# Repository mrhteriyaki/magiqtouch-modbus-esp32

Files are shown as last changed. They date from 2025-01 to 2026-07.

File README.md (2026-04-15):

# MagIQTouch Modbus

This project is an alternative to the official WiFi Module for the MagiqTouch system.  
It provides local access and control with a simple [REST API](Docs/Api.md).

### Home Assistant Integration: 
[https://github.com/mrhteriyaki/magiqtouch-modbus-esp32-ha](https://github.com/mrhteriyaki/magiqtouch-modbus-esp32-ha)

### Tested Configuration and Limitations: [Link](Docs/Tested.md)

### Hardware List: [Link](Docs/HardwareList.md)

### API Documentation: [Link](Docs/Api.md)

### Configuration Steps:
1. Download and Install [Arduino IDE](https://www.arduino.cc/en/software/)
2. Download the contents of the folder [ArduinoControlLAN-AirconControl].
3. Open the file ArduinoControlLAN-AirconControl.ino the Arduino IDE should open.
4. Under Tools, Board manager install the package "esp32 by Espressif Systems" 
5. Select Tools > Port and select the port related to the ESP32 module.
6. Click the Upload button (Right pointing Arrow).
7. Once the upload is completed, restart the device to ensure it resets after the upload.
8. The device will then broadcast a local WiFi network named 'ESP32-AIRCON', connect to it with passkey 'ExtraTasty123!'
9. Browse to http://esp32-aircon.local/wifi (or http://192.168.4.1/wifi)  
10. Enter in your normal WiFi network name/password and click save.  
The device will then reboot and join the WiFi network with the provided details.  
(If you enter in the incorrect wifi details, you will need to re-flash with the 'erase all flash' option enabled to clear the saved settings.)
11. Confirm the device is accessible by browsing to http://esp32-aircon.local/  
A JSON formatted response is displayed similar to [this example](Docs/Api.md).  

Wiring diagram for the device:  
(Note Ethernet boards use alternate pins)  

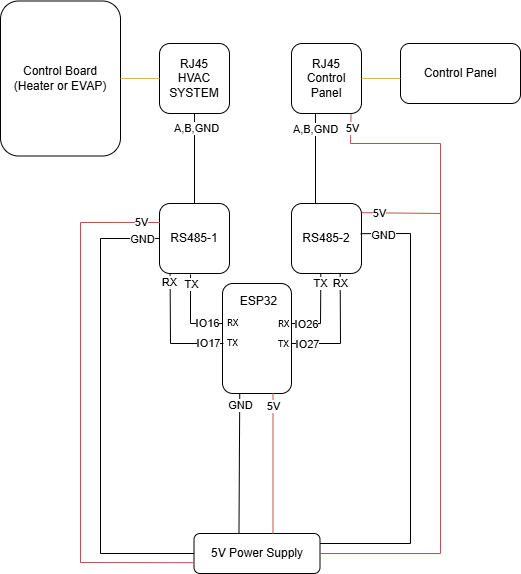
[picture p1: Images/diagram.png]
diagram


### For ethernet boards:
IO5  / RX2 -> RS485 Module 1 TX  
IO17 / TX2 -> RS485 Module 1 RX  
IO14 -> RS485 Module 2 TX  
IO15 -> RS485 Module 2 RX  

## RS485 to RJ45 Connector Wiring
The cables from the control panel and control board use a 6P6C male connector so that would be ideal.  
However I did not have one available in testing so for this will use a regular 8P8C Wall jack.

| RS485 Module | RJ45 Wire (A Wiring) |
|---|---|
| 5V (Control Panel Port Only) | Solid Green and Solid Orange |
| GND | Brown/White and Blue/White. |
| RS485 A | Solid Blue |
| RS485 B | Orange/White |

The standard 8P8C / RJ45 female ethernet wall jack can be used to connect to the cables to the device.  
The connector to the system board only requires A,B serial wires and ground.  
The connector to the control panel requires A,B, GND and 5V to power the panel.  

The 5v power should also be connected to the 5V Pin on the ESP32, to power both RS485 modules and one RJ45 ports for the control panel.  
The pinout on the rear of an RJ45 jack can vary with A/B positions, so make sure to match up the colours not positions in the image below. 

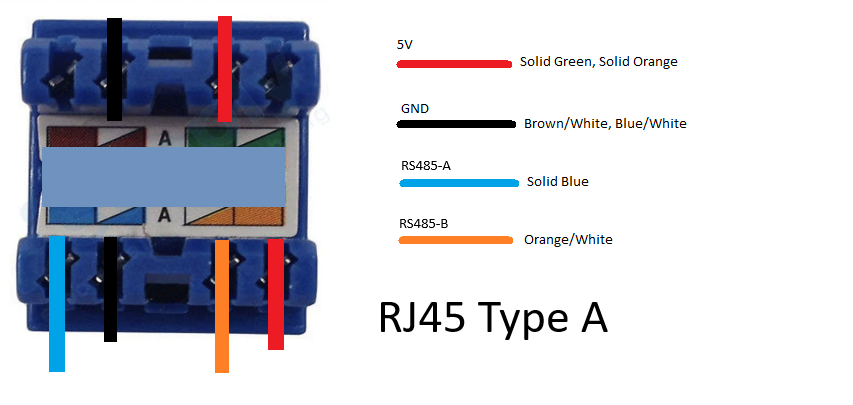
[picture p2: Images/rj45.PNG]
RJ45


Once you have wired up your device prepared, you should be able to connect it inbetween the heater unit control board and primary control panel.

If you are not replacing an existing WiFi module, you should be prompted when the module is detected to setup the WiFi settings, tap latter on this prompt.  
Try the the component configuration update if it does not show up in Settings -> Service.
[Instructions for detecting components](Docs/NewModule.md)

Here is my mess wired up inside a 3d printed housing, STL files for 3d printing available in the Housing-CAD-STL folder.  
(Image reflects older wiring with 9/10 pins, has been moved to use alternate pins since photo was taken.)  

insidebox

Mounted inside the return air wallspace:  
mounted

## More Technical Notes:

### Control Panel Wiring / Pin Information: [Link](Docs/ControllerWiring.md)

### MODBUS Information [Link](Docs/Modbus.md)

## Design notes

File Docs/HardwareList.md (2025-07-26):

[Back to Readme](../README.md)

Hardware List:
- ESP32 (Select One, these have been tested)
    - Wireless Options:
        - ESP32 WROOM-32 (Code runs on device, not tested connected to real system, should work)
        - FireBeetle ESP32 from [DFRobot](https://www.dfrobot.com/product-1590.html) - [Element14 Link](https://au.element14.com/dfrobot/dfr0478/firebeetle-esp32-iot-mcu-arduino/dp/3517881)
    - Wired Options:
        - WT32-ETH01 (Unit with Ethernet Port manufactured by Wireless Tag, requires a programmer [Link](https://core-electronics.com.au/usb-to-ttl-uart-rs232-serial-converter-module-pl2303hx-au-local-shipping.html))

- 2x RS485 Modules ([SeeedStudio Link](https://www.seeedstudio.com/Grove-RS485-p-2924.html) - 103020193)  Available in AUS at [Element14](https://au.element14.com/seeed-studio/103020193/serial-comm-board-rs485-arduino/dp/4007772) as "Serial Communication Board, RS485"
- 5V DC Power Supply

Cable / Connector List: 
- 2x RJ45 Connectors (Regular network jack, requires a 'punch down tool')
- Groove to Female Pin cables (SS110990028)
- 6P6C Cable if you are not replacing the original WiFi module.

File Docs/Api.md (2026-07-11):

[Back to Readme](../README.md)

## Web API Access and Control:

A GET Request to the module will return status info in JSON format.
Example of returned output.
```json
{
  "module_name": "ESP32-AIRCON",
  "uptime": "0d 00:05:11",
  "system_power": 0,
  "system_mode": 0,
  "target_temp": 20,
  "target_temp_zone2": 22,
  "evap_mode": 169,
  "evap_fanspeed": 0,
  "heater_mode": 0,
  "heater_fanspeed": 0,
  "heater_therm_temp": 16,
  "heater_zone1_enabled": 0,
  "heater_zone2_enabled": 0,
  "zone1_temp_sensor": 157,
  "zone2_temp_sensor": 20,
  "panel_command_count": 0,
  "automatic_clean_running": 0
}
```

Sending commands is simple using a POST request in plain/text to the path /command EG: http://192.168.20.112/command
The body should have a single command in the format setting=value

List of available commands, where x is the value.

| Command | Available Values | Function |
|---|---|---|
| power=x| on/off| System Power On or Off|
| zone1=x| on/off | Enable/Disable Zone 1 for Heater|
| zone2=x| on/off | Enable/Disable Zone 2 for Heater|
| fanspeed=x| 1-10 | Set Fan Speed for Fan, Cooler|
| mode=x| 0-4| Device Mode<br>0 = Fan Mode (External)<br>1 = Fan Mode (Recycle)<br>2 = Cooler (Manual)<br>3 = Cooler (Auto)<br>4 = Heater|
| temp=x| 0-28| Temperature Target for Cooler, Heater (Zone 1)
| temp2=x| 0-28| Temperature Target for Heater Zone 2|
| serial=x| on/off| Enables output of Modbus messages to Serial<br>Works with ModBusLogger tool on Serial message mode.|
| logging=x | 1.2.3.4 / off | Enable UDP stream of modbus messages for logging, supported with ModBusLogger tool.|

Additional endpoints are:
| URI Path | Function |
|---|---|
| /raw | Provides the raw output from the primary information modbus message sent from the panel to the IOT module. |
| /wifi | WiFi Configuration Setup Page |
| /network | Network information |
| /wifiupdate | Used by the wifi page to save WiFi settings to the device. |
| /clearsavedwifi | This will clear the saved WiFi settings and restore the default broadcasting AP. |

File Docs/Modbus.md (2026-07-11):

[Back to Readme](../README.md)

## MODBUS:
The [Modbus Codes.ods](../Modbus%20Codes.ods) file contains information about the modbus messages used on the network.
Messages are sent in pairs with a request and response message.
The document formats these by the Slave ID, Function Code, Request, Response with notes about the information found in these message pairs.

All devices are on the same single network, the primary / zone 1 control panel is the authorative device that sends the requests, all other devices respond.
Data that is requested from the control panel is typically sent with function 0x03 (read request) and information sent (write request) is with 0x10.

Known Slave IDs:
|Slave ID| Related Purpose|
|---|---|
|0x01 | Unknown|
|0x02 | Evap Unit|
|0x8C (140)| Unknown|
|0x8D (141)| Heater Unit|
|0x97 (151)| Control Panel 2|
|0xA5 (165)| Unknown|
|0xD4 (212)| Zone Controller by elimination � may also be shared heater|
|0xEB (235)| IOT WiFi Module|
|0xF4 (244)| Unknown|
|0xFA (250)| Unknown|
|0xFE (254)| Unknown|

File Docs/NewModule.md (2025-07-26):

[Back to Readme](../README.md)

## New Module Setup.
These are the steps to add the module to your system.
If you use the official WiFi IOT module these steps are not required as it should already be configured for your system.
Swapping from the official module to this ESP Module does not require reconfiguration.

1. Go to Settings -> General -> System Configuration (Bottom of the list)
If you are prompted for a code, try **7378** (this is the code printed in my manual, if it doesnt work check your manual as it has the service code).

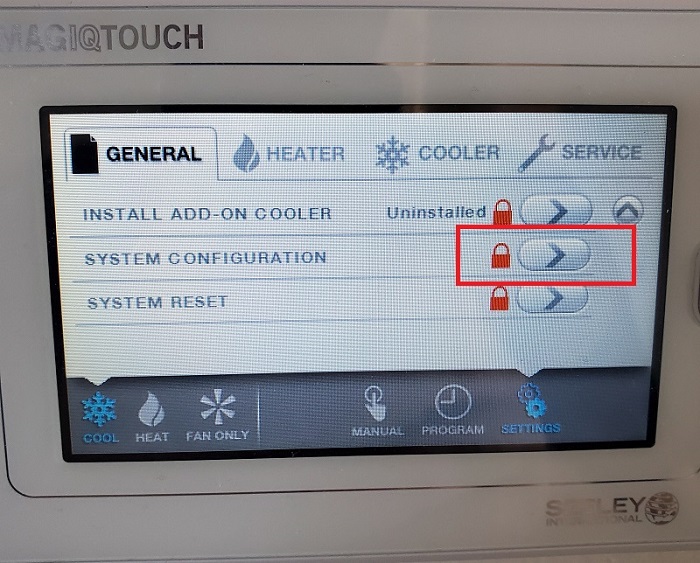
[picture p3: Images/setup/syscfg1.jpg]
syscfg1


2. Display or Modify existing System.
   
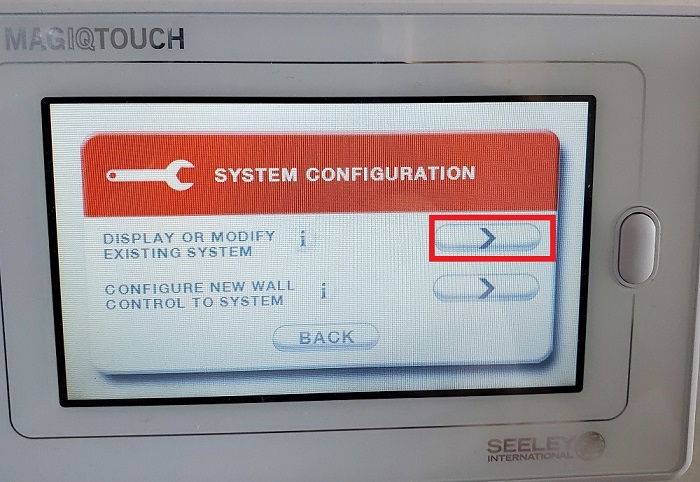
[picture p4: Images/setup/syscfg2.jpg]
syscfg2


3. Tap accept to start the system modbus scan.

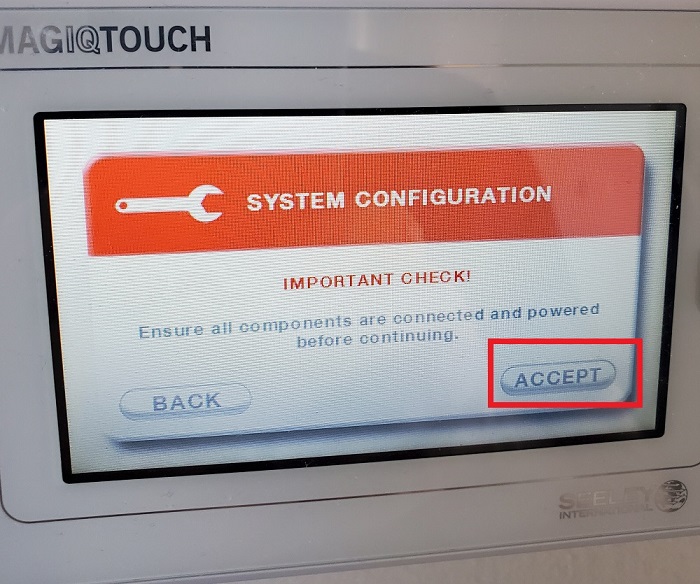
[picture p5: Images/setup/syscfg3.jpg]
syscfg3


4. It will scan for a couple minutes.

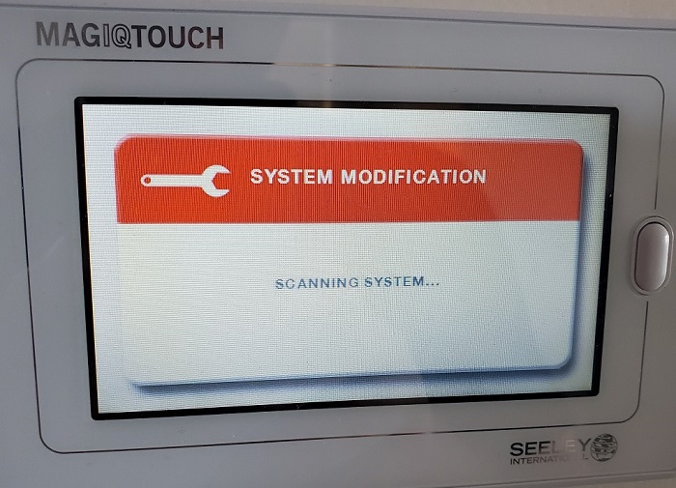
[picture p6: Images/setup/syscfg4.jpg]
syscfg4


5. When complete should display a summary of components on the system.

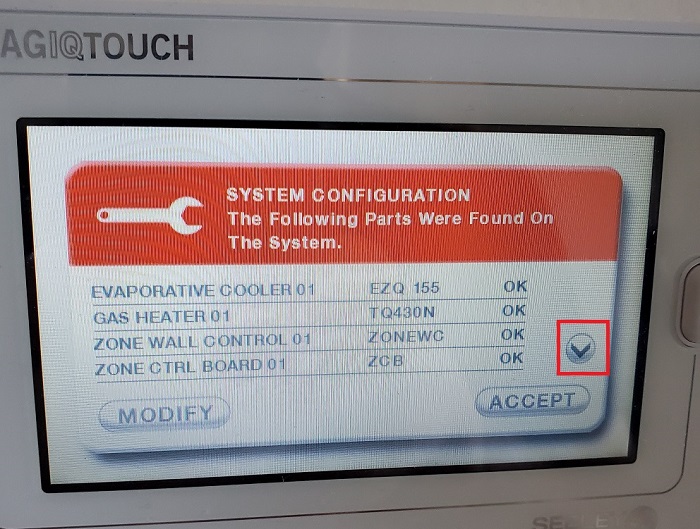
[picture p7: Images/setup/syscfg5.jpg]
syscfg5


6. The module should be detected as WiFi Smart Control, tap accept to complete the setup and the controller will restart.

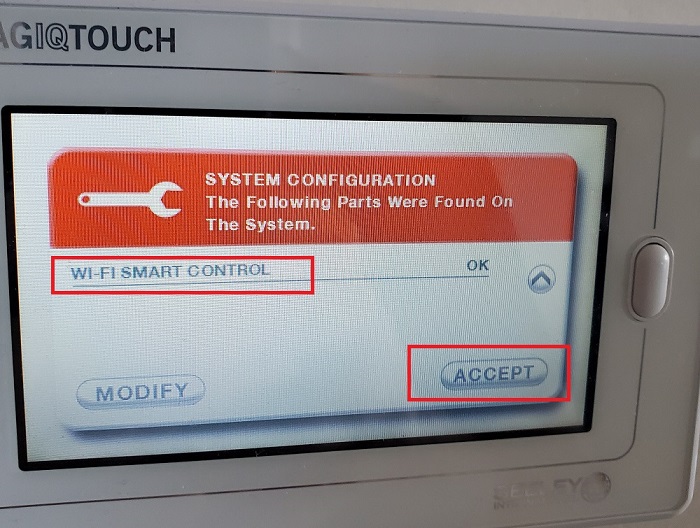
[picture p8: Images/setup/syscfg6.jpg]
syscfg6


7. Once the device startup is complete, it should be ready to go.
Note the WiFi status does not reflect the actual WiFi signal and uses a static code to fake the report.

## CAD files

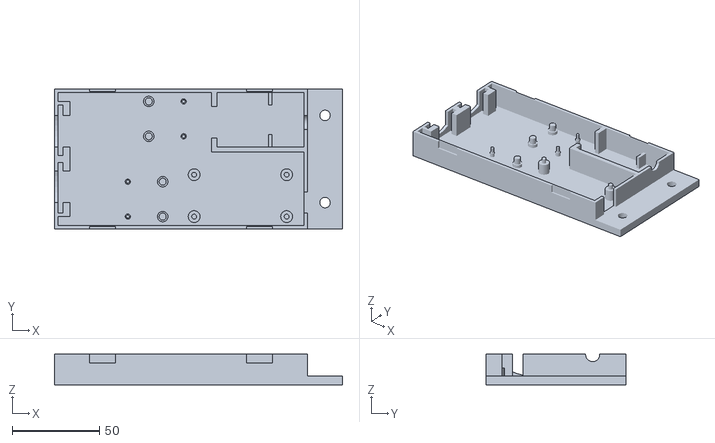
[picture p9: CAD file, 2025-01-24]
Housing-CAD-STL/Housing-Base.STL
165.0 x 80.0 x 17.5

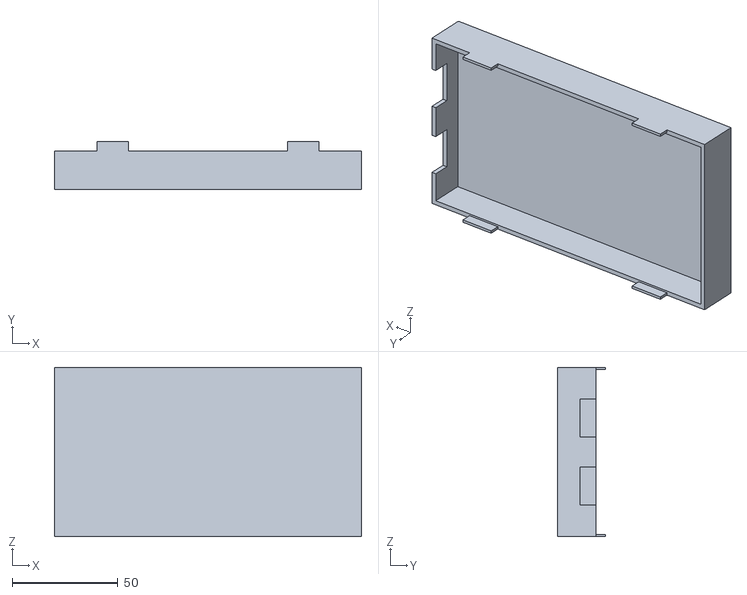
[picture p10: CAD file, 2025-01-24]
Housing-CAD-STL/Housing-CAP.STL
145.0 x 22.5 x 80.0

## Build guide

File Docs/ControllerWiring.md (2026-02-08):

[Back to Readme](../README.md)

Here's the pin layout for the original Connector too.  
Pinout

The GND and VCC are linked, purpose is likely to reduce cable resistance.  

| Pin | Wire Colour | Function |
|-----|---|---|
| 1 | Blue | VCC |
| 2 | Yellow | RS485-B  |
| 3 | Green | RS485-A  |
| 4 | Red | Ground |
| 5 | Black | VCC |
| 6 | White | Ground |

Tested VCC to Ground Voltage: 5.4V

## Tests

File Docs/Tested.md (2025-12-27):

[Back to Readme](../README.md)

## Tested and working with:  
- Evaporative Cooler (Breezair EZQ155)  
- Gas Heater (Braemar TQ430N)  
- 2 Zones  
- 2 Wall Controllers running software revision R719.  

## Known Limitations  
- Refrigerated Cooling not tested or supported.  
- Zones 3 & 4 not implemented. (Values are likely next in order from existing zone data)  
- Zone 1 temp sensor does not report correctly on non-temperature target modes  
  (Incorrectly reports temperature on app when using Fan modes or Cooler mode by fan speed).  
  Temp reporting issue occur with official module and app, not a limitation of this project.  
- Has only been tested with controller version R719.  
- WiFi controller status on control panel does not reflect actual ESP WiFi signal strength.  
- This project does not support the RF 'Wireless' Magiqtouch Controller as they do not support the official WiFi module.  
- On rare occasion module reports Fan / Cooler mode incorrectly as change is not sent by Controller messages.  
 (Example: Mode is swapped from Fan to Cooler on control panel, WiFi module will still think mode is on external fan)

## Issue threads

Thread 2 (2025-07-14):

Why two serial interfaces?

rlights, 2025-07-14:
I'm planning to build an interface in the near future and was very pleased to come across someone else having already done the hard work! So thankyou @mrhteriyaki for your efforts so far. The magiqtouch seems rather ubiquitous around Melbourne so this is helpful for a _lot_ of people.

However I'm very curious - why the two separate serial interfaces? The modbus interface shared between Seeley/ Braemar HVAC appliances (at least those compatible with the magiqtouch panels) is, well, a bus. Everything links together in parallel. As far as I can tell, the wifi module just offers two ports for physical convenience - so you don't need to purchase a link module as well, for most installations. I can't find anywhere a specification that one port or the other must face towards the appliance or the control panel. All together, I'm all but certain the two jacks are wired parallel.

Admittedly I can't find any information or images detailing the inside of the wifi module, but from looking at your code, the two interfaces are effectively back to back coupled via software anyway, with a background thread mirroring one to another & your write function writing to both simultaneously. Considering this I'm not entirely clear on what could be gained by gapping them like this instead of just using a single rs485 hardware interface and wiring the two jacks in parallel. Using a single interface would significantly reduce the complexity of both the hardware and software.

Have you had your original factory iot interface module apart? Care to share any images?

mrhteriyaki, 2025-07-14:
It's to determine the direction of the messages and which slave ID belongs to what.
I started with the monitor version and ran it as a simple proxy so it wouldn't cause any issues while the system ran normally.

So yeah it's probablly not needed outside of the development stage.

There's a fair few improvements that could be made but the interest has been low for actually building the project.
I think the barrier of actually assembling components is a non starter for many even in the home auto community.

I do have photos of the official board.
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

rlights, 2025-07-15:
Ah excellent, thanks for the confirmation. That looks like a rather well engineered board, it's rare to see consumer facing products that haven't been at least somewhat value optimised. But from what I've seen that's typical of Seeley - great hardware and lackluster software.
I would tend to agree that diy hardware can be a pretty big hurdle for a lot of HA folk. Might do something about that.

I gather from your various posts & comments that you have a limited number of system components to test the protocol against. I imagine most people will be in a similar situation with a slightly different selection, so it's well worth maintaining some monitor functionality. Perhaps it could even be the default first-boot mode so the datagrams can be sanity checked against what's on the wire before accidentally sending something inappropriate.
This would obviously also help a lot with extending the protocol definition for hardware we don't have.

There is one thing that might be reason enough to at least retain the possibility of two isolated serial ports:
I did originally consider using this interface module to feed in a temperature value from HA, instead of what is reported by the panel, but if only using a single serial interface that might be a lot harder. I think there are valid system configurations where the temperature probe in the panel is not used for zone temperature, but I'm really not clear on that, have you seen any data that confirms either way whether a different sensor can be configured to be the authoritative zone temperature?

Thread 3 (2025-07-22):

Compilation error on recent update

atomic10, 2025-07-22:
First off, thanks for this project. Home assistant control of my gas heater is exactly what I am looking for so I appreciate the time you have spent on building this.

With the update to V3 Espressif board library, I get a compile error with the following message
"Compilation error: 'DisconnectCheck' is not a member of 'LanController'"

I have updated all libraries that are in this project and I am using Arduino 2.3.6 IDE.
Also, Ihave tried with Espressif board library 3.0 & 3.2.1

If I comment the line out

```
void WebServerTask(void* parameter) {
  server.on("/", HTTP_GET, webRootResponse);
  server.on("/command", HTTP_POST, webCommandResponse);
  server.begin();

  while (true) {
    server.handleClient();
//    LanController::DisconnectCheck();
    vTaskDelay(1);
  }
}
```

It compiles, but Home assistant shows it as unavailable (was showing correct temp & correct set temp on previous version), and now when I go to the ESP32 IP address, it shows the JSON data, but appears to be adding data like a log file.
Below is a snippet

`{
  "module_name": "ESP32-HVAC-Control",
  "uptime": "00:00:11",
  "system_power": 0,
  "system_mode": 0,
  "target_temp": 0,
  "target_temp_zone2": 0,
  "evap_mode": 0,
  "evap_fanspeed": 0,
  "heater_mode": 0,
  "heater_fanspeed": 0,
  "heater_therm_temp": 0,
  "heater_zone1_enabled": 0,
  "heater_zone2_enabled": 0,
  "zone1_temp_sensor": 0,
  "zone2_temp_sensor": 0,
  "panel_command_count": 0,
  "automatic_clean_running": 0,
  "eb1008e60032_cp1data": "0,0,0,0,0,0,0,0,0,0,0,0,0,0,0,0,0,0,0,0,0,0,0,0,0,0,0,0,0,0,0,0,0,0,0,0,0,0,0,0,0,0,0,0,0,0,0,0,0,0,0,0,0,0,0,0,0,0,0,0,0,0,0,0,0,0,0,0,0,0,0,0,0,0,0,0,0,0,0,0,0,0,0,0,0,0,0,0,0,0,0,0,0,0,0,0,0,0,0,0,0,0,0,0,0,0,0,0,0"
}{
  "module_name": "ESP32-HVAC-Control",
  "uptime": "00:00:12",
  "system_power": 0,
  "system_mode": 0,
  "target_temp": 0,
  "target_temp_zone2": 0,
  "evap_mode": 0,
  "evap_fanspeed": 0,
  "heater_mode": 0,
  "heater_fanspeed": 0,
  "heater_therm_temp": 0,
  "heater_zone1_enabled": 0,
  "heater_zone2_enabled": 0,
  "zone1_temp_sensor": 0,
  "zone2_temp_sensor": 0,
  "panel_command_count": 0,
  "automatic_clean_running": 0,
  "eb1008e60032_cp1data": "0,0,0,0,0,0,0,0,0,0,0,0,0,0,0,0,0,0,0,0,0,0,0,0,0,0,0,0,0,0,0,0,0,0,0,0,0,0,0,0,0,0,0,0,0,0,0,0,0,0,0,0,0,0,0,0,0,0,0,0,0,0,0,0,0,0,0,0,0,0,0,0,0,0,0,0,0,0,0,0,0,0,0,0,0,0,0,0,0,0,0,0,0,0,0,0,0,0,0,0,0,0,0,0,0,0,0,0,0"
}{
  "module_name": "ESP32-HVAC-Control",
  "uptime": "00:00:13",
  "system_power": 0,
  "system_mode": 0,
  "target_temp": 0,
  "target_temp_zone2": 0,
  "evap_mode": 0,
  "evap_fanspeed": 0,
  "heater_mode": 0,
  "heater_fanspeed": 0,
  "heater_therm_temp": 0,
  "heater_zone1_enabled": 0,
  "heater_zone2_enabled": 0,
  "zone1_temp_sensor": 0,
  "zone2_temp_sensor": 0,
  "panel_command_count": 0,
  "automatic_clean_running": 0,
  "eb1008e60032_cp1data": "0,0,0,0,0,0,0,0,0,0,0,0,0,0,0,0,0,0,0,0,0,0,0,0,0,0,0,0,0,0,0,0,0,0,0,0,0,0,0,0,0,0,0,0,0,0,0,0,0,0,0,0,0,0,0,0,0,0,0,0,0,0,0,0,0,0,0,0,0,0,0,0,0,0,0,0,0,0,0,0,0,0,0,0,0,0,0,0,0,0,0,0,0,0,0,0,0,0,0,0,0,0,0,0,0,0,0,0,0"
}{
  "module_name": "ESP32-HVAC-Control",
  "uptime": "00:00:14",
  "system_power": 0,
  "system_mode": 0,
  "target_temp": 0,
  "target_temp_zone2": 0,
  "evap_mode": 0,
  "evap_fanspeed": 0,
  "heater_mode": 0,
  "heater_fanspeed": 0,
  "heater_therm_temp": 0,
  "heater_zone1_enabled": 0,
  "heater_zone2_enabled": 0,
  "zone1_temp_sensor": 0,
  "zone2_temp_sensor": 0,
  "panel_command_count": 0,
  "automatic_clean_running": 0,
  "eb1008e60032_cp1data": "0,0,0,0,0,0,0,0,0,0,0,0,0,0,0,0,0,0,0,0,0,0,0,0,0,0,0,0,0,0,0,0,0,0,0,0,0,0,0,0,0,0,0,0,0,0,0,0,0,0,0,0,0,0,0,0,0,0,0,0,0,0,0,0,0,0,0,0,0,0,0,0,0,0,0,0,0,0,0,0,0,0,0,0,0,0,0,0,0,0,0,0,0,0,0,0,0,0,0,0,0,0,0,0,0,0,0,0,0"
}`

Let me know if you need more info.

atomic10, 2025-07-23:
Thanks for the info. Will have a play over the weekend. The 1 degree increment is working as intended and temp sensor isn't working even with primary zone on, although I'm not convinced that I have everything perfect with my setup.

The heater I have is the TQS730. Single zone with no cooling.

It would be strange for them to change the Modbus structure of registers and coils between models but not impossible I guess. Tempted to get an IOT module just to be able to reverse engineer the messages and compare your findings.

Closed 2025-07-23.

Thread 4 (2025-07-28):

Connecting module makes all HVAC components "not detected"

unahmean, 2025-07-28:
Hi and thanks for your work on this project. I have wanted to integrate the MagiQtouch with HA for some time but was not a fan of the official wifi module so I was excited to try this.

I built this device a couple of months ago, but was not able to get it to work.

I have tried using both the Firebeetle ESP32 and a WT32-ETH01.
I have tried several different types of RS-485 modules that I had on hand (not the seed studio ones though) but they are otherwise identical on paper.
Flashed the ESP32 boards fine, they connect to the network and the webpage displays fine.
Wired everything up according to the diagram.
MagiQtouch software revision is R719.

The issue I am having is when I connect it inline with MagiQtouch controller and the heater control board, once it boots up, the controller reports that all of the components are not detected. The heater, evap cooler and an air sensor are all not detected. Scanning does nothing to fix the problem. Appears to not be chatting over modbus but I can't work out why.

Do I need to use the seed studio RS-485 modules? I have flashed and rewired/checked this thing so many times and spent days trying to troubleshoot.

I put it away out of frustration but pulled it out again over the weekend once I saw there was some work getting it to use Espressif version 3.x, but that did not help either.

Any ideas or help would be greatly appreciated.

mrhteriyaki, 2025-07-28:
That does sound like an issue with the RS485 modules and it's not relaying the messages if you're getting those errors.

Do the RS485 modules your using have a 120 ohm termination resistor built in?
The groove modules I'm using do, but I recall testing some other generic ones previously that did not so possibly that's the issue?

unahmean, 2025-07-29:
Hey thanks for that and I thought you were on to something here - the RS485 modules are meant to include the 120 ohm resistor, but I measured between A and B and they were not.

I checked out the schematic and to enable it you have to short out some solder pads. So I did this, and confirmed with a multimeter that it was now reading 120 ohms between A and B, but unfortunately the same issue still exists. Components not detected/not found with the device inline.

I also tried adding some actual metal film 120 ohm resistors to another pair of RS485 modules but no luck there either.

I will play some more but may have to get the grove rs485 modules to rule that out. Strange though as there really is not much to them.

mrhteriyaki, 2025-07-29:
The MAX485 has DE/RE in addition to RX/TX, but doesn't look like any have those so not the issue.

The HW-519 looks like it has LED indicators, do you see any flashes when the control panel is connected to it?
Even when it has that no components found error it's constantly sending messages so should see an indicator light up for RS485 RX.

Also have you tried swapping the A/B connections?

unahmean, 2025-08-01:
Thanks for your continued help! I saw the update to the documentation regarding A/B.

I can also confirm that on those modules the labelling is backwards - TX is acting as an input and RX as an output.

So I hooked it up correctly for my scenario, the MagiQtouch controller boots up and the heater, evap and air sensor are all found okay as per normal.

The issue I described two posts above remains.

1. Enter system configuration, scan for new components - only heater, evap and air sensor are detected.
2. Click Accept, reboots and returns to the default main screen.
3. Disconnect the RX and TX pins on the RS485 module leading to the heater's control board.
4. WiFi then appears on the main screen in green text. (note: this is without scanning for new components)
5. Other components heater, evap, air sensor drop off as not detected (obviously).
6. Reconnect RX and TX pins on the RS485 module leading to the heater's control board.
7. Green WiFi text disappears and an error message pops up "Wi-Fi Smart Control was not detected"
8. All other HVAC components are restored and functional.

I have tested with multiple RS485 modules, two ESP32 boards, with and without 120 ohm termination resistors.

I don't really want to factory reset the MagiQtouch controller but I have not tried that yet.

Any thoughts?

The air sensor is an "external air sensor" attached to the evap cooler on the roof. It doesn't appear that your setup has that, which is all I can think of hardware wise. I could climb up on the roof and disconnect it to test perhaps.

mrhteriyaki, 2025-08-01:
Glad to help, unfortunate it's hit another road bump.
RS485 issues seem resolved, If the devices are seen then it's proxying the messages.

My guess is there's some unexpected state the control panel is getting into when everything is connected and it's ignoring the IOT module.

I tested a reset myself and re-connected my esp32 module after the setup and it added itself after a half minute or so, the device update does not seem to be needed.

The air sensor does sound like a good next step to try, It would make sense that an external air sensor would change something in the IOT request/response packets that it's not accounting for.

Other options are to enable the serial output using a web request with serial=on
Then log all the modbus output from that and I can try to compare them to the existing known messages to see what's different.

mrhteriyaki, 2025-08-04:
Can you run the system configuration -> modify scan and send the serial output?

Looking at just the heater boot up process, it sends discovery messages for each of the slave IDs but skips over the ones for the IOT module (EB) so it doesn't seem to consider it part of the system.

I've got a few more tests I can run on my end but all going to take a while.
I'm a little bit suss on the RS485 modules being a problem, which ones did you end up using from the 3 you listed?

The basic relay process reads and then writes the byte to the other serial, but the processing can have timing issues if the RS485 boards are different to the Groove ones.
I have a feeling it may be failing to decode the messages and dropping them which wouldn't show up in the serial output, so the control panel may well be sending the messages for it to respond to.
The increased volume of messages with other modules also connected would explain why it drops off when the other devices are connected.

The software version on my heater unit is also listed as V1.09 and the messages all appear to be the same so I have a feeling the software is probably the same despite different model heater.

unahmean, 2025-08-05:
Thanks for looking into it and no worries if it is going to take some time to test on your end.

Here is the serial output for the system config -> modify, the scan process starts at line 32

[magiqtouch_scan_for_components.log](https://github.com/user-attachments/files/21595613/magiqtouch_scan_for_components.log)

As for the RS485 modules, I have tried multiple pairs of HW-519's and a pair of HW-726 - same behavior on all.

I may try and order some of the grove modules to eliminate that possibility, but these ones seem to work well otherwise.

Good to know that the heater PCB is likely the same.

mrhteriyaki, 2025-09-07:
Parts arrived a week or two ago, will let you know when I've tested them.

mrhteriyaki, 2025-09-13:
So tested it and HW-519 does work, with and without termination resistor interestingly.
There is a difference I found, the 3rd terminal on the RS side is not bridged to Ground.
Compared to the Groove module the ground on the RS side and UART side both have a 0 ohm resistance on the multimeter.
Have you bridged the RS reference terminal with GND using a separate wire?
How are your GND wires/points wired up?

mrhteriyaki, 2025-09-20:
On the HW-519 board to the control panel I bridged both grounds on the board itself with another wire.
The Grove modules have these internally bridged, the hw-519 seems to have some lightning protection component which I'm guessing splits it. As the control panel uses that same ground for power ground not just signal I would expect it cannot be isolated.

I went to use mine today (first time since putting these in) and it threw a comm error for the other system components.
Connecting the control panel directly works fine so not a system issue.
Swapped back to the Grove modules and it's working again.
There seems to be a few differences that don't make these boards a drop in replacement for the grove one.

unahmean, 2025-10-04:
So I had some Grove modules on order, they arrived, and I finally got around to trying them out in the past couple of days. As you have suggested - they worked fine. Everything is working properly now! Sorry for wasting your time with all of this but I guess something was learned through all of it.

Thanks again for your excellent work on this project and for your help, glad to finally have it fully functioning.

One extra thing I can let you know is that I am running my setup entirely on the heater control board's bus power. The ESP32 board, the modules and the magiqtouch screen all being powered with no issue. So no external power supply required for me which is great.

Feel free to close this issue now, unless you want any more info about anything.

Cheers!

mrhteriyaki, 2025-10-05:
Glad to hear it's working, am still a little surprised they worked.
Eventually I'll put the modules under the oscilloscope and see what it's doing at the wire level, guessing some sort of timing difference.

Closed 2025-10-05.

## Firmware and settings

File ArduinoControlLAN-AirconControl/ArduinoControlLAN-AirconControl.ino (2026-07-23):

// ESP32 Aircon Interface
// Board Library esp32 by Espressif Systems in use.

// Libraries.
#include <WebServer.h>
#include <ArduinoJson.h>
#include <esp_timer.h>
#include <HardwareSerial.h>
#include <WiFi.h>
#include <WiFiUdp.h>


#include "NetworkSettings.h"
#include "PinSettings.h"

// Max message size for modbus, reduce due to ram usage.
#define MAXMSGSIZE 256
#define MAXSLAVEID 30
#define GAPTHRESHOLD 50

WebServer server(80);


HardwareSerial SerialA(1);
HardwareSerial SerialB(2);

SemaphoreHandle_t msgSemaphore;

unsigned long s1previousMillis = 0;
uint8_t SerialAbuffer[MAXMSGSIZE];
int SerialAIndex = 0;

unsigned long s2previousMillis = 0;
uint8_t SerialBbuffer[MAXMSGSIZE];
int SerialBIndex = 0;

bool SerialOutputModbus = false;

bool MonitorMode = false;

// UDP Logging - mirrors SerialPrintMessage output to a remote host.
// Messages are queued here and sent from UdpLogTask so the modbus relay loop is never blocked by the network stack.
#define UDPLOGPORT 20000
#define UDPLOGQUEUELEN 8

struct UdpLogEntry {
  uint8_t data[MAXMSGSIZE + 2];  // +2 allows for CRC appended by SendMessage.
  int length;
  int serialID;
};

bool UdpLoggingEnabled = false;
IPAddress UdpLogHost;
WiFiUDP UdpLogger;
QueueHandle_t udpLogQueue;

// Aircon Control Variables.
bool SystemPower = false;
uint8_t FanSpeed = 1;
uint8_t SystemMode = 0;
uint8_t TargetTemp = 20;
uint8_t TargetTemp2 = 20;
bool HeaterZone1 = false;
bool HeaterZone2 = false;

// Aircon Info Variables.
uint16_t CommandInfo = 0x0;  // Increments on command change from Control Panel.
uint8_t SystemPowerInfo = 0x0;
uint8_t EvapModeInfo = 0x0;
uint8_t EvapFanSpeedInfo = 0x0;

uint8_t HeaterModeInfo = 0x0;
uint8_t HeaterFanSpeedInfo = 0x0;
uint8_t Zone1EnabledInfo = 0x0;
uint8_t Zone2EnabledInfo = 0x0;
uint8_t Zone1TempInfo = 0x0;
uint8_t Zone2TempInfo = 0x0;
uint8_t TargetTempInfo = 0x0;
uint8_t TargetTemp2Info = 0x0;
uint8_t ThermisterTempInfo = 0x0;
uint8_t AutomaticCleanRunning = 0x0;

// Derived from panel info. Reporting only.
bool initialSyncDone = false;  // No valid panel state known until first resync.
bool resyncPending = true;
uint8_t ReportedMode = 0x0;
uint8_t ReportedFanSpeed = 0x0;

bool sendCommand = false;
uint8_t IOTModuleCommandRequest[] = { 0xEB, 0x03, 0x0B, 0x0C, 0x00, 0x0D, 0x50, 0xE2 };
uint8_t x2vl = 0x9F;  // Increases for each command sent.
uint8_t x3vl = 0x21;  // WiFi DB Signal
uint8_t x4vl = 0x11;  // System Off 10 = On, 11 = Off.
uint8_t x5vl = 0x42;  // Cooler Mode 42 = Off, 02 = On
uint8_t x6vl = 0x43;  // Evap Fan setting.
uint8_t x7vl = 0x04;  // Unknown
uint8_t x8vl = 0x22;  // Heater Fan Settings.

uint8_t x10v = 0x24;
uint8_t x12v = 0x24;
uint8_t x14v = 0x00;  // zone control.

uint8_t x17v = 0x14;  // Zone 2 Temp - Default 20C
uint8_t x18v = 0x14;  // Zone 1 Temp

// Request for IOT Module info - Sends MAC address.
uint8_t IOTModuleInfoRequest[] = { 0xEB, 0x03, 0x03, 0xE4, 0x00, 0x05, 0xD3, 0x70 };
uint8_t IOTModuleInfoResponse[] = { 0xEB, 0x03, 0x0A, 0x01, 0x09, 0x01, 0x09, 0x70, 0x90, 0x2C, 0x65, 0x27, 0x0B };  // 13 bytes length, does not include CRC (0xA8, 0x11)

// 0xEB, 0x03, 0x0A, Version, MAC ADDRESS, 0xA8, 0x11
// Version is 0x01, 0x09, 0x01, 0x09
// MAC Address = 90:70:65:2C:0B:27

// Recurring responses that match the start of the request sent from CP1 - Function 10 Response.
uint8_t eb1005d80023[] = { 0xEB, 0x10, 0x05, 0xD8, 0x00, 0x23, 0x17, 0xED };  // CRC included.
uint8_t eb1005fb0021[] = { 0xEB, 0x10, 0x05, 0xFB, 0x00, 0x21, 0x67, 0xE6 };
uint8_t eb10061c002c[] = { 0xEB, 0x10, 0x06, 0x1C, 0x00, 0x2C, 0x16, 0x50 };
uint8_t eb1006480004[] = { 0xEB, 0x10, 0x06, 0x48, 0x00, 0x04, 0x57, 0x9E };
uint8_t eb10064C0038[] = { 0xEB, 0x10, 0x06, 0x4C, 0x00, 0x38, 0x16, 0x4E };
uint8_t eb100684002a[] = { 0xEB, 0x10, 0x06, 0x84, 0x00, 0x2A, 0x17, 0xBD };
uint8_t eb1006ae002a[] = { 0xEB, 0x10, 0x06, 0xAE, 0x00, 0x2A, 0x36, 0x75 };
uint8_t eb1006d80019[] = { 0xEB, 0x10, 0x06, 0xD8, 0x00, 0x19, 0x97, 0xBA };
uint8_t eb1008e50001[] = { 0xEB, 0x10, 0x08, 0xE5, 0x00, 0x01, 0x04, 0x94 };  // Info from CP1 to IOT for On/Off State.
uint8_t eb1008e60032[] = { 0xEB, 0x10, 0x08, 0xE6, 0x00, 0x32, 0xB4, 0x81 };  // Main info update from CP1 to IOT module.
uint8_t eb1008e60034[] = { 0xEB, 0x10, 0x08, 0xE6, 0x00, 0x34, 0x34, 0x83 };  // Same as above, for older version control panel.

#define eb1008e600_size 113
uint8_t eb1008e600_request[eb1008e600_size];

String jsonstring;
JsonDocument hvacJson;

#if defined(ARDUINO) && defined(__AVR__)
static PROGMEM const uint8_t table_crc_hi[] = {
#else
static const uint8_t table_crc_hi[] = {
#endif
  0x00, 0xC1, 0x81, 0x40, 0x01, 0xC0, 0x80, 0x41, 0x01, 0xC0,
  0x80, 0x41, 0x00, 0xC1, 0x81, 0x40, 0x01, 0xC0, 0x80, 0x41,
  0x00, 0xC1, 0x81, 0x40, 0x00, 0xC1, 0x81, 0x40, 0x01, 0xC0,
  0x80, 0x41, 0x01, 0xC0, 0x80, 0x41, 0x00, 0xC1, 0x81, 0x40,
  0x00, 0xC1, 0x81, 0x40, 0x01, 0xC0, 0x80, 0x41, 0x00, 0xC1,
  0x81, 0x40, 0x01, 0xC0, 0x80, 0x41, 0x01, 0xC0, 0x80, 0x41,
  0x00, 0xC1, 0x81, 0x40, 0x01, 0xC0, 0x80, 0x41, 0x00, 0xC1,
  0x81, 0x40, 0x00, 0xC1, 0x81, 0x40, 0x01, 0xC0, 0x80, 0x41,
  0x00, 0xC1, 0x81, 0x40, 0x01, 0xC0, 0x80, 0x41, 0x01, 0xC0,
  0x80, 0x41, 0x00, 0xC1, 0x81, 0x40, 0x00, 0xC1, 0x81, 0x40,
  0x01, 0xC0, 0x80, 0x41, 0x01, 0xC0, 0x80, 0x41, 0x00, 0xC1,
  0x81, 0x40, 0x01, 0xC0, 0x80, 0x41, 0x00, 0xC1, 0x81, 0x40,
  0x00, 0xC1, 0x81, 0x40, 0x01, 0xC0, 0x80, 0x41, 0x01, 0xC0,
  0x80, 0x41, 0x00, 0xC1, 0x81, 0x40, 0x00, 0xC1, 0x81, 0x40,
  0x01, 0xC0, 0x80, 0x41, 0x00, 0xC1, 0x81, 0x40, 0x01, 0xC0,
  0x80, 0x41, 0x01, 0xC0, 0x80, 0x41, 0x00, 0xC1, 0x81, 0x40,
  0x00, 0xC1, 0x81, 0x40, 0x01, 0xC0, 0x80, 0x41, 0x01, 0xC0,
  0x80, 0x41, 0x00, 0xC1, 0x81, 0x40, 0x01, 0xC0, 0x80, 0x41,
  0x00, 0xC1, 0x81, 0x40, 0x00, 0xC1, 0x81, 0x40, 0x01, 0xC0,
  0x80, 0x41, 0x00, 0xC1, 0x81, 0x40, 0x01, 0xC0, 0x80, 0x41,
  0x01, 0xC0, 0x80, 0x41, 0x00, 0xC1, 0x81, 0x40, 0x01, 0xC0,
  0x80, 0x41, 0x00, 0xC1, 0x81, 0x40, 0x00, 0xC1, 0x81, 0x40,
  0x01, 0xC0, 0x80, 0x41, 0x01, 0xC0, 0x80, 0x41, 0x00, 0xC1,
  0x81, 0x40, 0x00, 0xC1, 0x81, 0x40, 0x01, 0xC0, 0x80, 0x41,
  0x00, 0xC1, 0x81, 0x40, 0x01, 0xC0, 0x80, 0x41, 0x01, 0xC0,
  0x80, 0x41, 0x00, 0xC1, 0x81, 0x40
};

#if defined(ARDUINO) && defined(__AVR__)
#include <avr/pgmspace.h>
static PROGMEM const uint8_t table_crc_lo[] = {
#else
static const uint8_t table_crc_lo[] = {
#endif
  0x00, 0xC0, 0xC1, 0x01, 0xC3, 0x03, 0x02, 0xC2, 0xC6, 0x06,
  0x07, 0xC7, 0x05, 0xC5, 0xC4, 0x04, 0xCC, 0x0C, 0x0D, 0xCD,
  0x0F, 0xCF, 0xCE, 0x0E, 0x0A, 0xCA, 0xCB, 0x0B, 0xC9, 0x09,
  0x08, 0xC8, 0xD8, 0x18, 0x19, 0xD9, 0x1B, 0xDB, 0xDA, 0x1A,
  0x1E, 0xDE, 0xDF, 0x1F, 0xDD, 0x1D, 0x1C, 0xDC, 0x14, 0xD4,
  0xD5, 0x15, 0xD7, 0x17, 0x16, 0xD6, 0xD2, 0x12, 0x13, 0xD3,
  0x11, 0xD1, 0xD0, 0x10, 0xF0, 0x30, 0x31, 0xF1, 0x33, 0xF3,
  0xF2, 0x32, 0x36, 0xF6, 0xF7, 0x37, 0xF5, 0x35, 0x34, 0xF4,
  0x3C, 0xFC, 0xFD, 0x3D, 0xFF, 0x3F, 0x3E, 0xFE, 0xFA, 0x3A,
  0x3B, 0xFB, 0x39, 0xF9, 0xF8, 0x38, 0x28, 0xE8, 0xE9, 0x29,
  0xEB, 0x2B, 0x2A, 0xEA, 0xEE, 0x2E, 0x2F, 0xEF, 0x2D, 0xED,
  0xEC, 0x2C, 0xE4, 0x24, 0x25, 0xE5, 0x27, 0xE7, 0xE6, 0x26,
  0x22, 0xE2, 0xE3, 0x23, 0xE1, 0x21, 0x20, 0xE0, 0xA0, 0x60,
  0x61, 0xA1, 0x63, 0xA3, 0xA2, 0x62, 0x66, 0xA6, 0xA7, 0x67,
  0xA5, 0x65, 0x64, 0xA4, 0x6C, 0xAC, 0xAD, 0x6D, 0xAF, 0x6F,
  0x6E, 0xAE, 0xAA, 0x6A, 0x6B, 0xAB, 0x69, 0xA9, 0xA8, 0x68,
  0x78, 0xB8, 0xB9, 0x79, 0xBB, 0x7B, 0x7A, 0xBA, 0xBE, 0x7E,
  0x7F, 0xBF, 0x7D, 0xBD, 0xBC, 0x7C, 0xB4, 0x74, 0x75, 0xB5,
  0x77, 0xB7, 0xB6, 0x76, 0x72, 0xB2, 0xB3, 0x73, 0xB1, 0x71,
  0x70, 0xB0, 0x50, 0x90, 0x91, 0x51, 0x93, 0x53, 0x52, 0x92,
  0x96, 0x56, 0x57, 0x97, 0x55, 0x95, 0x94, 0x54, 0x9C, 0x5C,
  0x5D, 0x9D, 0x5F, 0x9F, 0x9E, 0x5E, 0x5A, 0x9A, 0x9B, 0x5B,
  0x99, 0x59, 0x58, 0x98, 0x88, 0x48, 0x49, 0x89, 0x4B, 0x8B,
  0x8A, 0x4A, 0x4E, 0x8E, 0x8F, 0x4F, 0x8D, 0x4D, 0x4C, 0x8C,
  0x44, 0x84, 0x85, 0x45, 0x87, 0x47, 0x46, 0x86, 0x82, 0x42,
  0x43, 0x83, 0x41, 0x81, 0x80, 0x40
};

void lockVariable() {
  xSemaphoreTake(msgSemaphore, portMAX_DELAY);
}

void unlockVariable() {
  xSemaphoreGive(msgSemaphore);
}

void setup() {
  Serial.begin(9600);
  Serial.println("OK");
  // Set Serial, Baud Rate, 8 bit no parity, RX,TX
  SerialA.begin(9600, SERIAL_8N1, SERIAL1_RX, SERIAL1_TX);
  SerialB.begin(9600, SERIAL_8N1, SERIAL2_RX, SERIAL2_TX);

  msgSemaphore = xSemaphoreCreateMutex();

  udpLogQueue = xQueueCreate(UDPLOGQUEUELEN, sizeof(UdpLogEntry));
  xTaskCreate(UdpLogTask, "UdpLogTask", 4096, NULL, 1, NULL);

  // Prefill messages used for webserver.
  memset(eb1008e600_request, 0, eb1008e600_size);

  // Start Modbus Proxy
  xTaskCreatePinnedToCore(ModbusRelayLoop, "ModbusRelayLoop", 16384, NULL, 1, NULL, 1);

  LanController::Setup();

  //MAC address reporting to panel.
  uint8_t mac[6];
  WiFi.macAddress(mac);
  IOTModuleInfoResponse[7] = mac[1];
  IOTModuleInfoResponse[8] = mac[0];
  IOTModuleInfoResponse[9] = mac[3];
  IOTModuleInfoResponse[10] = mac[2];
  IOTModuleInfoResponse[11] = mac[5];
  IOTModuleInfoResponse[12] = mac[4];

  xTaskCreate(WebServerTask, "WebServerTask", 16384, NULL, 1, NULL);
}

void loop() {
  vTaskDelay(100);
}

void WebServerTask(void *parameter) {
  server.on("/", HTTP_GET, webRootResponse);
  server.on("/raw", HTTP_GET, webDebugResponse);
  server.on("/command", HTTP_POST, webCommandResponse);
  server.on("/network", HTTP_GET, NetworkInfoResponse);

  //WiFi Setup.
  server.on("/wifi", HTTP_GET, wifiSetupResponse);
  server.on("/wifiupdate", HTTP_POST, wifiUpdate);
  server.on("/clearsavedwifi", HTTP_GET, wifiClearSaved);

  //Management.
  server.on("/restart", HTTP_GET, restartDevice);

  server.begin();

  while (true) {
    server.handleClient();
    vTaskDelay(1);
  }
}

void ModbusRelayLoop(void *parameter) {
  while (true) {
    relaySerial(SerialA, SerialB, SerialAbuffer, SerialAIndex, s1previousMillis, 1);
    relaySerial(SerialB, SerialA, SerialBbuffer, SerialBIndex, s2previousMillis, 2);
  }
}

void relaySerial(HardwareSerial &inputSerial, HardwareSerial &outputSerial, uint8_t *buffer, int &index, unsigned long &previousMillis, int serialPort) {
  while (inputSerial.available()) {
    uint8_t incomingByte = inputSerial.read();
    outputSerial.write(incomingByte);

    // Gap Threshold of time between last byte, mark as message complete.
    unsigned long currentMillis = millis();
    if (index > 0 && currentMillis - previousMillis > GAPTHRESHOLD) {
      index = 0;
    }
    previousMillis = currentMillis;  // Save current time byte is received.

    if (index == MAXMSGSIZE) {
      if (SerialOutputModbus) {
        Serial.println("ERROR: Buffer limit reach - MAXMSGSIZE limit is a problem. Resync triggered.");
      }
      index = 0;
    }

    // Save byte to buffer and process message.
    buffer[index++] = incomingByte;
    if (ProcessMessage(buffer, index, serialPort)) {
      index = 0;
    }
  }
}

void webRootResponse() {
  lockVariable();

  hvacJson.clear();
  hvacJson["module_name"] = LanController::NET_HOSTNAME;
  hvacJson["uptime"] = getUptimeFormatted();
  hvacJson["system_power"] = SystemPowerInfo;
  hvacJson["system_mode"] = ReportedMode;
  hvacJson["target_temp"] = TargetTempInfo;
  hvacJson["target_temp_zone2"] = TargetTemp2Info;
  hvacJson["evap_mode"] = EvapModeInfo;
  hvacJson["evap_fanspeed"] = EvapFanSpeedInfo;
  hvacJson["heater_mode"] = HeaterModeInfo;
  hvacJson["heater_fanspeed"] = HeaterFanSpeedInfo;
  hvacJson["heater_therm_temp"] = ThermisterTempInfo;
  hvacJson["heater_zone1_enabled"] = Zone1EnabledInfo;
  hvacJson["heater_zone2_enabled"] = Zone2EnabledInfo;
  hvacJson["zone1_temp_sensor"] = Zone1TempInfo;
  hvacJson["zone2_temp_sensor"] = Zone2TempInfo;
  hvacJson["panel_command_count"] = CommandInfo;
  hvacJson["automatic_clean_running"] = AutomaticCleanRunning;

  unlockVariable();

  serializeJsonPretty(hvacJson, jsonstring);
  server.send(200, "application/json", jsonstring);
}

void webDebugResponse() {
  lockVariable();
  hvacJson.clear();

  // Main Information Modbus message for system status.
  char eb1008char[eb1008e600_size * 4];
  eb1008char[0] = '\0';  // Initialize the string as empty
  for (size_t i = 0; i < eb1008e600_size; i++) {
    char buffer[4];
    sprintf(buffer, "%u", eb1008e600_request[i]);
    strcat(eb1008char, buffer);
    if (i < eb1008e600_size - 1) {
      strcat(eb1008char, ",");
    }
  }

  hvacJson["eb1008e600_cp1data"] = eb1008char;

  unlockVariable();

  serializeJsonPretty(hvacJson, jsonstring);
  server.send(200, "application/json", jsonstring);
}

void NetworkInfoResponse() {
  int signal_val = WiFi.RSSI();
  lockVariable();
  hvacJson.clear();
  hvacJson["WIFI_IP"] = WiFi.localIP().toString();
  hvacJson["WIFI_dBm"] = signal_val;
  hvacJson["WIFI_MAC"] = WiFi.macAddress();

  unlockVariable();

  serializeJsonPretty(hvacJson, jsonstring);
  server.send(200, "application/json", jsonstring);
}

void webCommandResponse() {
  if (server.hasArg("plain")) {         // Check if the body exists
    String body = server.arg("plain");  // Get the body of the POST request
    if (SerialOutputModbus) {
      Serial.println("Web request: " + body);
    }
    lockVariable();
    if (body.indexOf("power=on") != -1) {  // Check if "D1" is in the body
      SystemPower = true;
      if (SerialOutputModbus) {
        Serial.println("System Power set to True");
      }
    } else if (body.indexOf("power=off") != -1) {
      SystemPower = false;
      if (SerialOutputModbus) {
        Serial.println("System Power set to false");
      }
    } else if (body.indexOf("zone1=on") != -1) {
      HeaterZone1 = true;
      if (SerialOutputModbus) {
        Serial.println("Enabled Zone 1");
      }
    } else if (body.indexOf("zone1=off") != -1) {
      HeaterZone1 = false;
      if (SerialOutputModbus) {
        Serial.println("Disabled Zone 1");
      }
    } else if (body.indexOf("zone2=on") != -1) {
      HeaterZone2 = true;
      if (SerialOutputModbus) {
        Serial.println("Enabled Zone 2");
      }
    } else if (body.indexOf("zone2=off") != -1) {
      HeaterZone2 = false;
      if (SerialOutputModbus) {
        Serial.println("Disabled Zone 2");
      }
    } else if (body.indexOf("serial=on") != -1) {
      SerialOutputModbus = true;
      Serial.println("Serial Output Enabled");
    } else if (body.indexOf("serial=off") != -1) {
      SerialOutputModbus = false;
      Serial.println("Serial Output Disabled");
    } else if (body.indexOf("monitor=on") != -1) {
      MonitorMode = true;
      Serial.println("Monitor Mode On");
    } else if (body.indexOf("monitor=off") != -1) {
      MonitorMode = false;
      Serial.println("Monitor Mode Off");
    } else if (body.startsWith("logging=")) {
      String host = body.substring(8);
      host.trim();
      if (host == "off") {
        UdpLoggingEnabled = false;
        Serial.println("UDP Logging Disabled");
      } else if (UdpLogHost.fromString(host)) {
        UdpLoggingEnabled = true;
        Serial.println("UDP Logging Enabled to " + UdpLogHost.toString() + ":" + String(UDPLOGPORT));
      } else {
        UdpLoggingEnabled = false;
        Serial.println("UDP Logging host invalid: " + host);
      }
    } else if (body.startsWith("send=")) {
      SendMessageString(body.substring(5));
    } else if (body.startsWith("fanspeed=")) {
      int number = body.substring(9).toInt();
      if (number >= 1 && number <= 10) {
        FanSpeed = number;
      }
      if (SerialOutputModbus) {
        Serial.println("Fan speed set to " + String(FanSpeed));
      }
    } else if (body.startsWith("mode=")) {
      int number = body.substring(5).toInt();
      if (number >= 0 && number <= 5) {
        SystemMode = number;
      }
      if (SerialOutputModbus) {
        Serial.println("System mode set to " + String(SystemMode));
      }
    } else if (body.startsWith("temp=")) {
      int number = body.substring(5).toInt();
      if (number >= 0 && number <= 28) {
        TargetTemp = number;
      }
      if (SerialOutputModbus) {
        Serial.println("Target Temp set to " + String(TargetTemp));
      }
    } else if (body.startsWith("temp2=")) {
      int number = body.substring(6).toInt();
      if (number >= 0 && number <= 28) {
        TargetTemp2 = number;
      }
      if (SerialOutputModbus) {
        Serial.println("Target Temp set to " + String(TargetTemp2));
      }
    }
    sendCommand = true;  // Force command update
    unlockVariable();

    server.send(200, "text/plain", "OK");
  } else {
    server.send(400, "text/plain", "No body received.");
    if (SerialOutputModbus) {
      Serial.println("Failed to send reply to command - no body received.");
    }
  }
}

bool ProcessMessage(uint8_t msgBuffer[], int msgLength, int SerialID) {
  if (msgLength < 4) {  // Skip messages below min length.
    return false;
  }
  // CRC Message Validation
  uint16_t crcraw = (msgBuffer[msgLength - 2] << 8 | msgBuffer[msgLength - 1]);
  uint16_t expectedcrc = modbusCRC(msgBuffer, msgLength - 2);
  if (crcraw == expectedcrc) {
    if (SerialOutputModbus || UdpLoggingEnabled) {
      SerialPrintMessage(msgBuffer, msgLength, SerialID);
    }

    // Seperate Processing functions for each message source/destination.

    IoTModuleMessageProcess(msgBuffer, msgLength);  // IOT Module
    // EvapInfoUpdate(msgBuffer, msgLength); //Evap Unit
    // HeaterInfoUpdate(msgBuffer, msgLength); //Heater Unit
    // Panel1Info(msgBuffer, msgLength); //Control Panel 1
    Panel2Info(msgBuffer, msgLength);  // Control Panel 2.

    return true;
  }
  return false;
}

void EvapInfoUpdate(uint8_t *msgBuffer, int msgLength) {
  uint8_t evapInfoResponse[] = { 0x02, 0x03, 0x40 };
  if (checkPattern(msgBuffer, evapInfoResponse, 3)) {
    // Aircon unit info - Pump State, Active fan mode?
  }
}

void HeaterInfoUpdate(uint8_t *msgBuffer, int msgLength) {
  // Active Fan speed?
}

void Panel1Info(uint8_t *msgBuffer, int msgLength) {
  // On/Off.
  // Zone1 On/Off.
  // Temp Sensor
}

void Panel2Info(uint8_t *msgBuffer, int msgLength) {
  if (msgLength != 7) {
    return;
  }

  // Temp Sensor
  uint8_t panelInfoResponse[] = { 0x97, 0x03, 0x02 };
  if (checkPattern(msgBuffer, panelInfoResponse, 3)) {
    lockVariable();
    Zone2TempInfo = msgBuffer[3];
    unlockVariable();
  }
}

void SerialPrintMessage(uint8_t *msgBuffer, int msgLength, int SerialID) {
  if (SerialOutputModbus) {
    Serial.print("S");
    Serial.print(SerialID);
    Serial.print(" ");
    for (int i = 0; i < (msgLength - 2); i++) {
      Serial.print(msgBuffer[i], HEX);
      Serial.print(" ");
    }
    Serial.print(msgBuffer[msgLength - 2], HEX);
    Serial.print(" ");
    Serial.print(msgBuffer[msgLength - 1], HEX);
    Serial.println();
  }

  // Queue a copy for UDP logging, sent by UdpLogTask.
  // Never blocks; drops the message if the queue is full.
  if (UdpLoggingEnabled && msgLength <= (int)sizeof(((UdpLogEntry *)0)->data)) {
    UdpLogEntry entry;
    memcpy(entry.data, msgBuffer, msgLength);
    entry.length = msgLength;
    entry.serialID = SerialID;
    xQueueSend(udpLogQueue, &entry, 0);
  }
}

void UdpLogTask(void *parameter) {
  UdpLogEntry entry;
  static char line[(MAXMSGSIZE + 2) * 3 + 8];  // "S1" + " FF" per byte + newline.
  while (true) {
    if (xQueueReceive(udpLogQueue, &entry, portMAX_DELAY) == pdTRUE) {
      if (!UdpLoggingEnabled) {
        continue;
      }
      int pos = snprintf(line, sizeof(line), "S%d", entry.serialID);
      for (int i = 0; i < entry.length; i++) {
        pos += snprintf(line + pos, sizeof(line) - pos, " %X", entry.data[i]);
      }
      line[pos++] = '\n';
      UdpLogger.beginPacket(UdpLogHost, UDPLOGPORT);
      UdpLogger.write((uint8_t *)line, pos);
      UdpLogger.endPacket();
    }
  }
}

static uint16_t modbusCRC(uint8_t *buffer, uint16_t buffer_length) {
  uint8_t crc_hi = 0xFF; /* high CRC byte initialized */
  uint8_t crc_lo = 0xFF; /* low CRC byte initialized */
  unsigned int i;        /* will index into CRC lookup */
  while (buffer_length--) {
    i = crc_hi ^ *buffer++; /* calculate the CRC  */
#if defined(ARDUINO) && defined(__AVR__)
    crc_hi = crc_lo ^ pgm_read_byte_near(table_crc_hi + i);
    crc_lo = pgm_read_byte_near(table_crc_lo + i);
#else
    crc_hi = crc_lo ^ table_crc_hi[i];
    crc_lo = table_crc_lo[i];
#endif
  }
  return (crc_hi << 8 | crc_lo);
}

uint8_t IOTModuleStatusRequest[] = { 0xEB, 0x03, 0x02, 0x58, 0x00, 0x12, 0x53, 0x66 };
void SendIOTModuleStatus() {
  uint8_t wifi = 0x21;  // WiFI Connected 00, Disconnected = 21
  if (WiFi.status() == WL_CONNECTED) {
    wifi = 0x0;
  }

  uint8_t IOTModuleStatusResponse[] = { 0xEB,
                                        0x03, 0x24, 0x00, wifi, 0x52, 0x4D, 0x32, 0x48,
                                        0x00, 0x00, 0x00, 0x00, 0x00, 0x00, 0x00, 0x00,
                                        0x00, 0x00, 0x00, 0x00, 0x00, 0x00, 0x00, 0x00,
                                        0x00, 0x00, 0x00, 0x00, 0x00, 0x00, 0x00, 0x00,
                                        0x00, 0x00, 0x00, 0x00, 0x04, 0x00 };
  if (!MonitorMode) {
    SendMessage(IOTModuleStatusResponse, 39, true);
  }
}
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

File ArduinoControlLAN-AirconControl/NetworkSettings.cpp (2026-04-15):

#include "NetworkSettings.h"

bool mdns_started = false;
Preferences LanController::prefs;

void LanController::Setup() {

  Network.onEvent(NetworkConnectedEvent);

#if USING_WIRED_ETHERNET == 1 && ESP_ARDUINO_VERSION_MAJOR >= 3
  // The argument order changed in esp32-arduino v3+
  ETH.begin(ETH_PHY_LAN8720, 1, 23, 18, 16, ETH_CLOCK_GPIO0_IN);
#elif USING_WIRED_ETHERNET == 1
  ETH.begin(1, 16, 23, 18, ETH_PHY_LAN8720, ETH_CLOCK_GPIO0_IN);
#endif

  //Use longer WiFi scan method for network selection.
  //Default fast-scan method selects WAP by lowest channel number.
  WiFi.setScanMethod(WIFI_ALL_CHANNEL_SCAN);
  WiFi.setSortMethod(WIFI_CONNECT_AP_BY_SIGNAL);
#if USING_WIRED_ETHERNET == 1
  String WiFiHostname = String(NET_HOSTNAME) + "-WiFi";
  WiFi.setHostname(WiFiHostname.c_str());
#else
  WiFi.setHostname(NET_HOSTNAME);
#endif

  String ssid_load, passkey_load;
  loadWiFiCredentials(ssid_load, passkey_load);
  if (ssid_load.isEmpty() || passkey_load.isEmpty()) {
    WiFi.softAP(NET_HOSTNAME, softAPpassword);
  } else {
    WiFi.begin(ssid_load, passkey_load);
  }

  xTaskCreate(ReconnectLoop, "ReconnectLoop", 4096, NULL, 1, NULL);
  if (OTA_ENABLED) {
    xTaskCreate(OTATask, "OTATask", 4096, NULL, 1, NULL);
  }
}

void LanController::saveWiFiCredentials(String &ssid, String &passkey) {
  prefs.begin("wifi", false);  // "wifi" = namespace, false = read/write
  prefs.putString("wifi_ssid", ssid);
  prefs.putString("wifi_key", passkey);
  prefs.end();

  //Restart device to use new details.
  ESP.restart();
}

void LanController::loadWiFiCredentials(String &ssid, String &password) {
  prefs.begin("wifi", true);  // true = read-only
  ssid = prefs.getString("wifi_ssid", "");
  password = prefs.getString("wifi_key", "");
  prefs.end();
}

void LanController::ReconnectLoop(void* parameter) {
  while (true) {
    if (WiFi.status() != WL_CONNECTED) {
      Serial.println("WiFi disconnected, attempting reconnect...");
      WiFi.begin();
    }
    vTaskDelay(10000);
  }
}

void LanController::NetworkConnectedEvent(arduino_event_id_t event) {
  switch (event) {
    case ARDUINO_EVENT_ETH_START:
      ETH.setHostname(NET_HOSTNAME);
      break;

    case ARDUINO_EVENT_ETH_GOT_IP:
      Serial.print("ETH MAC: ");
      Serial.print(ETH.macAddress());
      Serial.print(", IPv4: ");
      Serial.print(ETH.localIP());
      if (ETH.fullDuplex()) {
        Serial.print(", FULL_DUPLEX");
      }
      Serial.print(", ");
      Serial.print(ETH.linkSpeed());
      Serial.println("Mbps");
      StartMDNS();
      break;

    case ARDUINO_EVENT_ETH_DISCONNECTED:
      Serial.println("ETH Disconnected");
      break;

    case ARDUINO_EVENT_WIFI_STA_GOT_IP:
      Serial.println("WiFi connected");
      Serial.println("IP address: ");
      Serial.println(WiFi.localIP());
      StartMDNS();
      break;
  }
}

void LanController::StartMDNS() {

  if (mdns_started) {
    MDNS.end();
  }
  if (MDNS.begin(NET_HOSTNAME)) {
    MDNS.addService("http", "tcp", 80);
    MDNS.addService("magiqaircon", "tcp", 80);
    mdns_started = true;
  }
}

void LanController::OTATask(void* parameter) {
  ArduinoOTA.onStart([]() {
              String type = ArduinoOTA.getCommand() == U_FLASH ? "sketch" : "filesystem";
              // NOTE: if updating SPIFFS this would be the place to unmount SPIFFS using SPIFFS.end()
              Serial.println("Start updating " + type);
            })
    .onEnd([]() {
      Serial.println("\nEnd");
    })
    .onProgress([](unsigned int progress, unsigned int total) {
      Serial.printf("Progress: %u%%\r", (progress / (total / 100)));
    })
    .onError([](ota_error_t error) {
      Serial.printf("Error[%u]: ", error);
      if (error == OTA_AUTH_ERROR) Serial.println("Auth Failed");
      else if (error == OTA_BEGIN_ERROR) Serial.println("Begin Failed");
      else if (error == OTA_CONNECT_ERROR) Serial.println("Connect Failed");
      else if (error == OTA_RECEIVE_ERROR) Serial.println("Receive Failed");
      else if (error == OTA_END_ERROR) Serial.println("End Failed");
    });

  ArduinoOTA.setHostname(NET_HOSTNAME);
  ArduinoOTA.setPassword(OTA_PASSWORD);

  ArduinoOTA.begin();
  while (true) {
    ArduinoOTA.handle();
    vTaskDelay(20);
  }
}

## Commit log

2025-01-19 Add project files.
    [Modbus Codes.xlsx]
2025-01-24 Update readme and cadfiles.
    [Housing-Base.STL, Housing-CAP.STL]
2025-01-30 Update docs to with temp issue.
    [Modbus Codes.xlsx]
2025-03-23 Add automatic_clean_running status. Fix json headers for use with home assistant.
    [ArduinoControlLAN-AirconControl.ino]
2025-03-26 bugfix - additional zone state reporting.
    [Modbus Codes.xlsx]
2025-04-14 Add wired ethernet module.
    Update network settings header/cpp for common support.
    Readme updated.
2025-05-01 Add uptime to json output for restart detection. Adjust json variable from dynamic to static with larger limit. Add delay to relay loop to reduce cpu lockups. Update sample output.
2025-05-03 Swap delay type to reduce delay in loop.
    [ArduinoControlLAN-AirconControl.ino]
2025-07-14 Stable running esp board library v3.
2025-07-23 Missing disconnect code in network settings. Bugfix uptime string with long uptime.
    [ArduinoControlLAN-AirconControl.ino, NetworkSettings.cpp]
2025-07-31 Correct error in documentation - reverse A/B for RS485 wiring.
2025-08-01 Revise readme - setup process. Update modbus document with SSID data.
    [Modbus Codes.xlsx]
2026-01-24 Monitor mode added. Adjust WiFi scan mode for ESP32 to fix Wireless AP selection issues in multi-ap env.
    [ArduinoControlLAN-AirconControl.ino, NetworkSettings.cpp]
2026-02-08 update controllor wiring doc to include a/b
2026-03-09 Initial testing support for older panel software version - response code eb1008e60034 added. Increase size of info messages support as it is 4 bytes longer.
    Merge ethernet module version into single version.
    mDNS discovery added.
    StaticJsonDocument deprecation fixed.
    [ArduinoControlLAN-AirconControl.ino, NetworkSettings.cpp]
2026-04-15 MT panel will show MAC and WiFi signal db level from ESP radio. Replaced static password requirement with WiFi setup process. (Not via panel) Minor memory stack improvements.
    [ArduinoControlLAN-AirconControl.ino, NetworkSettings.cpp]
2026-07-11 Bugfix system mode calculation - occasional desync from actual system mode - moved from eb 10 08 - e5 to e6 as trigger. Added logging over udp stream. Monitor updated to support udp stream. Modbus co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
    [Modbus Codes.ods, Modbus Codes.xlsx]
2026-07-23 Bugfix - panel command reset by status update trigger on remote module. Revise status to use reportedmode and allow re-sync period after command from panel.
    [ArduinoControlLAN-AirconControl.ino]
2026-07-23 Target temp rule adjusted. Remove +11 degree offset from base value for heaters for non-zoned system target.
    [Modbus Codes.ods]
